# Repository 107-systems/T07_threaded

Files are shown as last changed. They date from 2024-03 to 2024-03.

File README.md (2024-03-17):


T07 threaded
===
T07 threaded is a tracked mobile outdoor robotics platform.

### Repositories
* [t07_robot](https://github.com/107-systems/t07_robot): ROS control code for T07 robot.
* [t07_docker](https://github.com/107-systems/t07_docker): Dockerfile and scripts to run T07 control software on [Pika Spark](https://pika-spark.io/).
* [t07_teleop](https://github.com/107-systems/t07_teleop): Keyboard based teleoperation for the T07 mobile outdoor robot.

### 3D-Renderings

<p align="center">
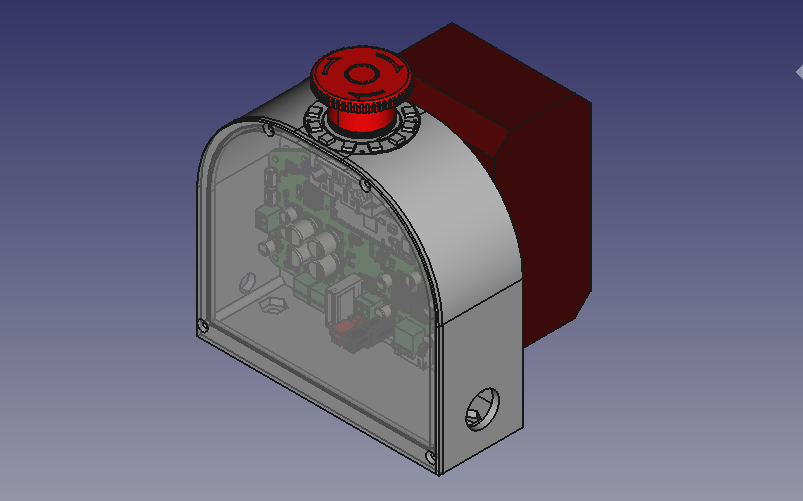
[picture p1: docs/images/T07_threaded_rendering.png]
   
</p>

## Introduction

The T07 is an outdoor robotics platform intended for participation in contests like Robotem Rovne, Roboorienteering or Robotour but also for general robotic experiments.

There is also a mounting option for the [mandeye-controller](https://github.com/JanuszBedkowski/mandeye_controller).

## Electronics and firmware

There are mounting holes for a Raspberry Pi or a [Pika Spark](https://docs.pika-spark.io/) on the controller standoff.

[CyphalRobotController07/CAN](https://github.com/generationmake/CyphalRobotController07-CAN) is the main controller board.

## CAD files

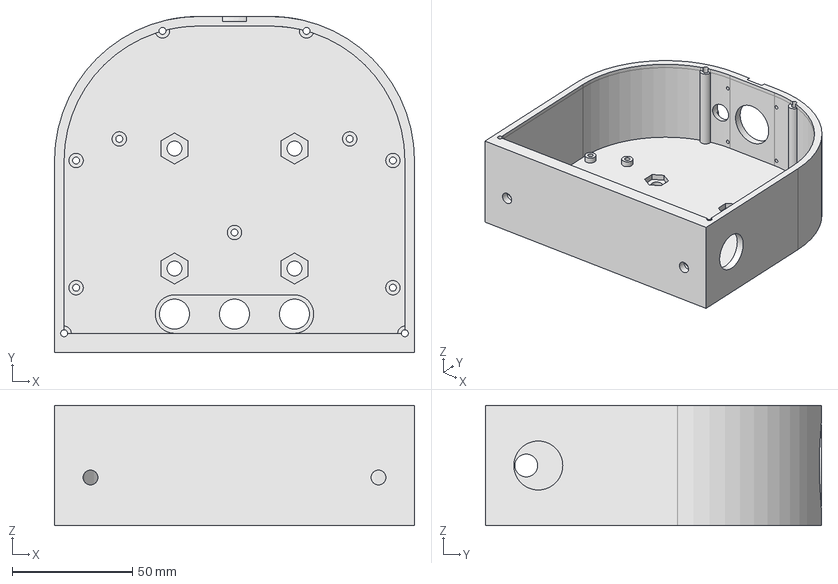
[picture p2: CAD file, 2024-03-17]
freecad_source/parts/T07_threaded_enclosure.FCStd
150.0 x 140.0 x 50.0 mm

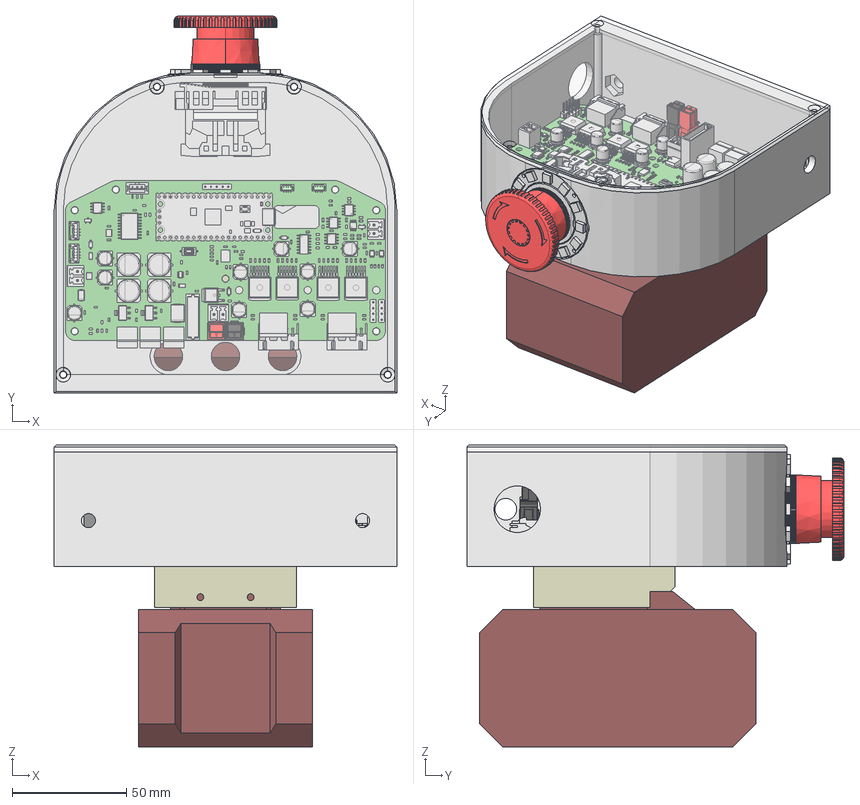
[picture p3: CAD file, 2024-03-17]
freecad_source/T07_threaded.FCStd
150.0 x 165.0 x 132.0 mm
CyphalRobotController07-CAN PCB
battery_adapter_einhell_x-change
einhell_power_x-change_4_0ah
Emergency button AR22FOR
Emergency button AR22FOR001
Emergency button AR22FOR002
Emergency button AR22FOR003
Emergency button AR22FOR004
Emergency button AR22FOR005
top
Adafruit_Neopixel_12_50mm

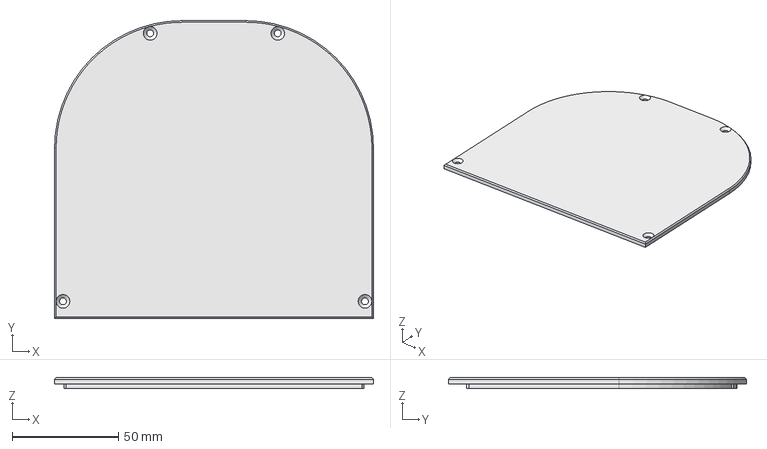
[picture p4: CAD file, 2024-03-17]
productiondata/T07_threaded_enclosure-top.step
150.0 x 140.0 x 5.00 mm

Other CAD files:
productiondata/T07_threaded_enclosure-Body.step
productiondata/T07_threaded_enclosure-Body.stl
productiondata/T07_threaded_enclosure-top.stl

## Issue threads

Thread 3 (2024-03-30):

rework holes

generationmake, 2024-03-30:
<a href="https://107-systems.org/">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</a>

### :bug: Bug Report

**Describe the bug**

increase holes for motor connector because connectors don't fit through holes.
move hole for on/off connector slightly up because screw nut collides with enclosure
decrease wall thickness at side holes so that the rubber sealing fits in

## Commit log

2024-02-13 added first CAD data
    [T07_threaded.FCStd, T07_threaded_enclosure-Body.step, T07_threaded_enclosure.FCStd]
2024-02-13 added rendering
    [T07_threaded.FCStd]
2024-03-04 added some mounting holes
    [T07_threaded_enclosure-Body.step, T07_threaded_enclosure-Body.stl, T07_threaded_enclosure.FCStd]
2024-03-04 added enclosure top
    [T07_threaded_enclosure-top.step, T07_threaded_enclosure-top.stl, T07_threaded_enclosure.FCStd]
2024-03-05 added holes for on/off switch, position for LED ring
    [T07_threaded_enclosure-Body.step, T07_threaded_enclosure-Body.stl, T07_threaded_enclosure.FCStd]
2024-03-05 updated 3d model of complete setup
    [T07_threaded.FCStd]
